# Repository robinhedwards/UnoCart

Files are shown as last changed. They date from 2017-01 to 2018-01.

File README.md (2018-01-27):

UnoCart
=======
The UnoCart is an SD-card multicart for the Atari 8-bit (XL & XE), supporting ROMs,CARs,XEXs and some ATR files.
It is the little brother of the [Ultimate Cart](https://github.com/robinhedwards/UltimateCart/).

The multicart is based on a STM32F4 microcontroller running at 168MHz. This is (just) fast enough to respond to requests
from the Atari's 6502 bus clocked at approximately 2 MHz. Files are loaded from SD card into the STM32F4's SRAM allowing
emulation of Atari cartridges up to 128k in size.

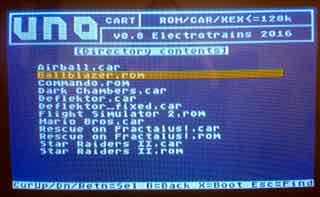
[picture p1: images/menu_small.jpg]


When the Atari first boots, the cartridge displays a list of all the files on the SD card. When a ROM or CAR file is
selected, the cartridge will then emulate the selected cartridge type. The UnoCart supports standard 8k and 16k ROMS,
XEGS cartridges up to 128k in size, AtariMax 1mbit, Bounty Bob, OSS cartridges and many more.

XEX files (Atari executables) are also supported using a XEX loader built into the cartridge.

The cartridge can also emulate a disk drive on an Atari with with at least 64k. It does this by installing a Soft OS into
the Atari which then redirects D1: to the ATR file selected from the menu. Access for D2: upwards continue to be directed
to the SIO port as normal.
Many games will not work, due to the soft OS technique used. However it is possible to boot to a DOS 2.5 ATR file,
do some programming in BASIC and save your program back to the ATR file. ATR files up to 16Meg in size are supported.

Hardware
--------
The UnoCart was first designed using a STM32F407 DISCOVERY board. An article describing how to build an UnoCart using
this board was published in [Excel Magazine](http://excel-retro-mag.co.uk) issue #4.
You can also get a PDF of the article [here](https://github.com/robinhedwards/UnoCart/blob/master/UnoCart_EXCEL4.pdf).

I have also designed a custom PCB for the UnoCart pictured here. If you are interested in a ready to use cartridge (complete with
3d printed case) these are currently being produced by Marlin Bates in the USA: [website](http://www.thebrewingacademy.com/)
or email thebrewingacademy@gmail.com.

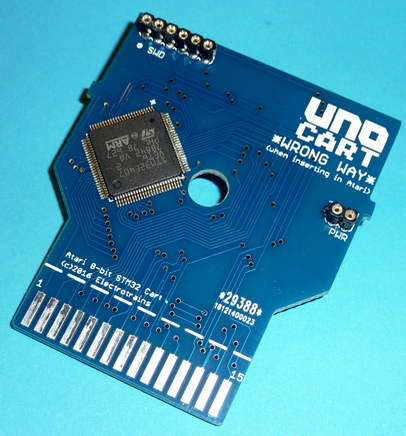
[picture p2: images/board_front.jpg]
Bottom/Back of PCB when inserted in Atari

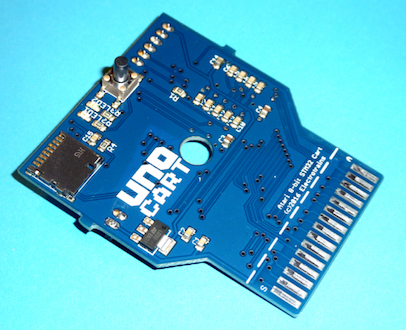
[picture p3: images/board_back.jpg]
Top/Front of PCB when inserted in Atari


Firmware
--------
The UnoCart firmware is open source under a GPL license and is hosted here.

Credits
-------
* Design, hardware and firmware by Robin Edwards (electrotrains at atariage)
* XEX loader and OS modifications by Jonathan Halliday (flashjazzcat at atariage)
* Altirra LLE OS used with permision from Avery Lee (phaeron at atariage)
* German translation of user manual by Florian D (FlorianD at atariage)
* Production by Marlin Bates (MacRorie at atariage)

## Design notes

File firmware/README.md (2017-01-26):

The current UnoCart firmware (v1.2)

For use with ST-Link device and STM32 ST-Link utility (see the user guide for more details).

Changelog

* 2017-01-26 v1.2 Fixed XEX loader bug, added support for CTRL+Cursor keys (CTRL+LEFT = back).
* 2016-12-04 v1.1 Initial version for beta test.

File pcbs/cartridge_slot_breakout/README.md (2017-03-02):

Eagle board file for Atari cartridge slot breakout PCB, which breaks out the cartridge slot to 6 x 5 pin headers (male or female).
For use with Atari XL or XE.

On an XE, the side where the connector is labelled S-A should be facing upwards.
On an XL, the S-A side should be facing forwards.

IMPORTANT - on an XL, you should remove the cartridge slot flaps, or insert something in the slot to keep the flaps away from the PCB. Otherwise you risk a short circuit.

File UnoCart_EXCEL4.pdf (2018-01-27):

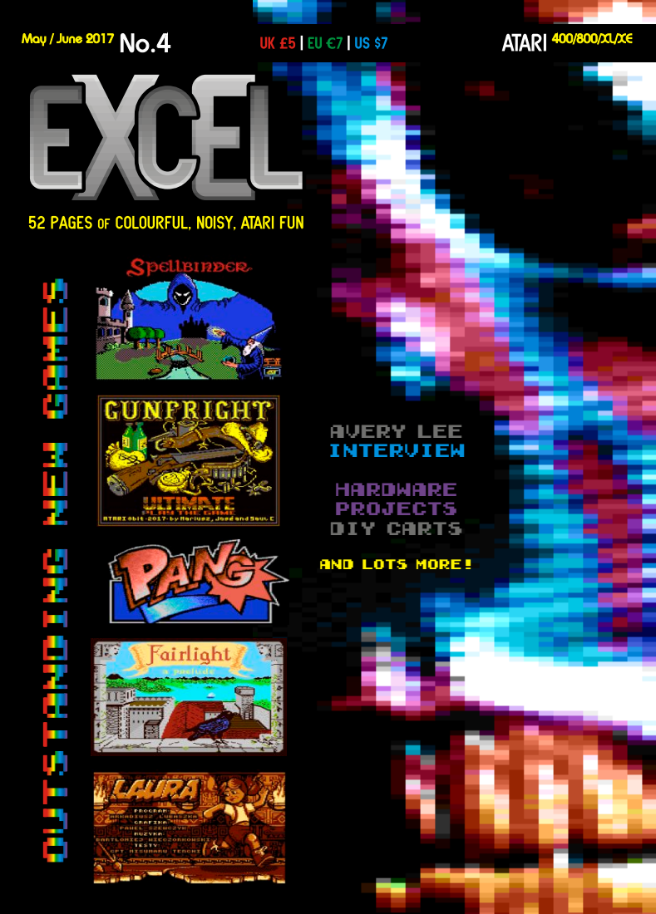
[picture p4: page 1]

OUTSTANDING NEW GAMES

You can read more about the capabilies of the UnoCart by downloading the User Guide which is available as a PDF on the project website (2).

### WHAT YOU NEED

ST32F407 Discovery board. There are two versions of this board – an older one (order code STM32F4DISCOVERY) and a newer version (order STM32F407G-DISC1). Either is suitable and costs about £16.

Cartridge slot breakout board. I’ve designed a PCB that slides into the cartridge slot, allowing the signals to be easily accessed with jumper wires. The PCB can be ordered from a PCB manufacturer using the breakout PCB file on the project website (2). For readers in the USA, the bits of the past website (3) offers a similar board for sale at $15.

I’ve got a number of these boards spare for readers of the magazine, so the cheapest opon is to contact me (robin.edwards@gmail.com) to see if I’ve got any le. Cost would be £3 + P&P.

2.54mm male header pins (x30). If you don’t have these already, they are cheaply (£1) available from eBay and all electronics suppliers, and need to be soldered to the cartridge breakout PCB (see below).

Female to female jumper wires (x36). You’ll need 30 to hook up the cartridge port to the discovery board, and another 6 to hook up the SD card. Mine are 10cm long; a bit longer would have been easier (£2 on eBay).

SD (or micro SD) card breakout board. These are available cheaply on ebay and most online electronics hobbyist websites (£3-5). Since the discovery board is 3.3v (the same as SD cards) there is no need for a more expensive board with 5v conversion (though you can use those too). Something like (4) is ideal. I used a 5v regulated one (5) which I had in my components box.

Make sure the pins on the board you buy are labeled with the SPI connecons –DI, DO, SCK (or CLK) & CS.

Programming the Firmware
First you need to download the UnoCart firmware (a file with a .hex extension) from the project website (2) and save it.

To program this file to the board, download the ST-Link soware (6) and install it. This should also install the ST-Link driver to your computer. With that done you can connect the Discovery board to your computer using a USB cable. Start the ST-Link soware and select

# Building a UNOcart by Robin Edwards

Aer wring about DIY standard 8k and 16k EEPROM based cartridges in my previous column, I wanted to do a follow up arcle with building instrucons for a more flexible and modern mul-cart design.

A mul-cart allows you to put lots of different games (and other soware) on one cartridge and choose what to use from a built-in menu. Many different mul-carts have been made for our Atari 8-bits and most of them require lengthy programming of a (large) EEPROM every me you want to change the contents of the cartridge. Programming is usually done on the Atari with a SIO device as the source. This means these cartridges are not so useful as stand-alone devices and also makes them less than ideal for quickly trying out new soware.
With those issues in mind, a couple of years ago I designed the Ulmate Cart (1) an open-source mul-cart that uses an SD card for storage and is capable of emulang almost all types of cartridge ever released for the Atari 8-bit, including many other mul-carts. But the Ulmate cart requires some costly parts and advanced soldering techniques so it’s not something that most people could easily build by themselves.

So for this arcle, I’m going to describe how to build my newest project – the UnoCart, a mul-cart I designed for readers of Excel magazine. It aims to be cheap (under £30) and easy to put together, yet provide a modern way to access a wide range of soware (old and new) on an unmodified Atari XL or XE.

In many ways, the UnoCart is the lile brother of the Ulmate Cart – it emulates a wide range of cartridges (up to 128k in size), can launch XEX files (executables) and ATR files (disk images), all from a micro SD card.
It does all this using a single chip (hence the name of the project!) – a fast STM32407 ARM microcontroller running at 168MHz. This is fast enough to keep up with the 6502 bus and supply data to the Atari whenever it accesses the cartridge port. These microcontrollers are available ready to use on cheap development boards, so the only soldering involved in this project is making a simple breakout board so we can connect it up to the Atari’s cartridge port.

Target/Connect. Then select Target/Program & Verify and select the .hex file you downloaded. When that completes, the UnoCart firmware will be flashed to your discovery board. Select
Target/Disconnect and then unplug the USB cable – now you’re ready to start wiring things up.

Building
First solder the male header pins to the breakout board PCB, by breaking the header strip up into 6
pieces with 5 pins. Insert these into
the holes in the breakout board and
solder them into place. Noce that the board is labelled S-A on one side and 1-15 on the other. The S-A side of the board will be facing upwards (XE) or towards you (XL) when inserted in an Atari.

For use on XE machines - you’ll need to solder the pins so you will be able to aach the jumper wires to the top of the board (as seen in the picture).

On an XL machine, you may prefer to solder the pins the other way round, so the wires will be leading out towards the back of your machine rather than over the keyboard.

With that done, its me to wire up the 30 connecons on the breakout board to the appropriate pins on the discovery board. The table above shows the connecons you should make. Please check them carefully, since incorrect wiring may damage the discovery board, the Atari or both!

(1) You must disconnect the USB cable from the discovery board when plugging in the device to your Atari. The discovery board must be powered by the Atari via the cartridge slot only, or you will probably destroy the MMU chip on your Atari.
(2) On an XL you should remove the cartridge slot flaps or otherwise prevent them touching the breakout board to prevent a short circuit.

Now we can plug the device into the Atari and check our wiring so far - making sure that the USB cable is not plugged in (see noce above). If all has gone well, you should see the “error can’t read SD card” screen (as shown on the right) when you power up the Atari with the board plugged in. If not, turn the power off quickly and find the mistake in your wiring.

Now we can hook up the SD card connecons.

Connect as follows:

First power up. We haven’t wired up the SD card yet so the error is to be expected!

6

Assembly is now complete – you should be able to plug the board into your Atari, power up and see a list of all the loadable files and directories on the SD card. Use the cursor keys and return to select a XEX, ROM, CAR or ATR file and enjoy!

If everything is working, its now worth downloading the full instrucon manual for the UnoCart from the project website.

Troubleshoong p - Some SD cards fail to inialize without a pull-up resistor on DO. Either try a different SD card or add this pull up by connecng any resistor in the range of 10k to 100k (I used 47k) between DO and 3V. You can see I have soldered this directly onto the SD card breakout board in the picture.

## Links

(1) github.com/robinhedwards/UlmateCart/
(2) github.com/robinhedwards/UnoCart/
(3) www.bitsohepast.com
(4) www.hobbytronics.co.uk/microsd-breakout
(5) www.hobbytronics.co.uk/microsd-card-regulated-v2
(6) www.st.com/en/embedded-soware/stsw-link004.html

Cartridge slot breakout PCB and header strip (le) and assembled version for use
on an Atari XE (right).
The cheapest way to get one is to contact the author and see if he has any spares!

The STM32F407 DISCOVERY board (older version). A lot of power for £16!

### The finished UnoCart plugged into

the back of a 65XE.

The UnoCart menu when everything is working.

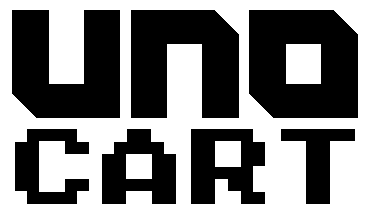
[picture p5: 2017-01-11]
images/UNOcart.bmp

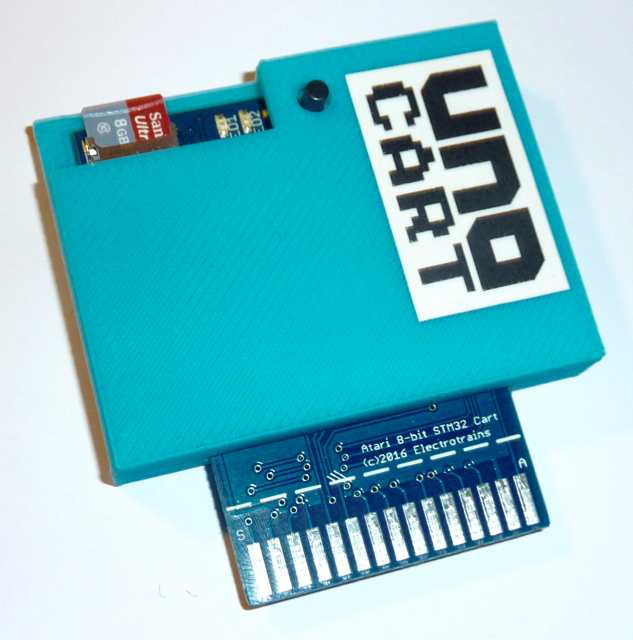
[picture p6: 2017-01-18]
images/cased.jpg

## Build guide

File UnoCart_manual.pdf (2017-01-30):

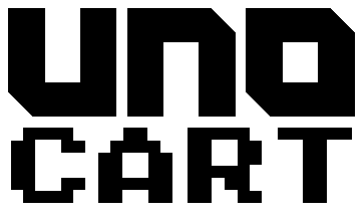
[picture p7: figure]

# Instruction Manual

Revision 1.5 30/1/2017

Atari XL/XE microSD multi-cart

Quick Start
The UnoCart is an Atari cartridge emulator and XEX file launcher. It supports files up to 128k in size. First, copy XEX, CAR and ROM files to a microSD card and insert it into the cartridge. Then insert the cartridge in the Atari 8-bit with the label/SD card slot facing forwards (Atari XL) or upwards (Atari XE). If the board is uncased, check you’ve got it the right way round. Power on the Atari. Use the cursor up and down keys to select an item and press Return to start it. Menu
The menu allows you to navigate the files on a microSD card and select a title to use. Use the cursor up, down and [Return] keys to select items. Press [B] to go back to the parent directory. Press [ESC] to search for a file. Press [X] to disable the cartridge and boot normally (e.g. from a SIO device) – this allows you to leave the cartridge plugged in. Indicator Lights
The red led indicates the cartridge is functioning correctly and is powered. When the menu is active, the green light will indicate SD card access. After a title is selected from the menu, the green light indicates that the cartridge is active.
Reset Button
Press the reset button (next to the SD card slot) to reset the cartridge. This will generally cause the Atari to crash, and the reset button on the Atari can then be pressed to return to the cartridge menu.
CAR Files & ROM Files
CAR files and ROM files both contain the data for a cartridge. However CAR files have an additional 16 bytes header containing the cartridge type making it clearly identifiable to the UnoCart. In contrast, the cartridge type of a ROM file is ambiguous – e.g. an 8k ROM file could be a standard 8K cartridge, or an 8k OSS cartridge.
ROM Files
Plain ROM files are supported, but since these files are raw cartridge dumps, the UnoCart will decide what type of cartridge they come from based on the file size only. The table below shows what types will be used.
ROM File Size | Cartridge Type
8k | Standard Atari 8k
16k | Standard Atari 16k
32k | Atari XEGS 32k
64k | Atari XEGS 64k
128k | Atari XEGS 128k
Supported Cartridge Types (CAR files)
Description | CAR Type(s)
Standard Atari 8k | 1
Standard Atari 16k | 2
Atari XEGS 32-128k | 12-14
AtariMax 1mbit (128k) | 41
Switchable XEGS 32-128k | 33-35
Megacart 16-128k | 26-29
Bounty Bob | 18

Williams 32k, 64k | 8, 22
OSS 8k | 44
OSS 16k (034M) | 3
OSS 16k (043M) | 45
OSS 16k (type B) | 15
SIC!Cart (128k only) | 54
SDX 64k | 11
Diamond 64k | 10
Express 64k | 9
SDX 128k | 43
Blizzard 16k | 40
Converting to CAR format
Utilities are available to convert ROM/BIN files into the CAR file format. The ROM2CAR utility available on the Ultimate cart website provides an easy drag and drop interface: https://github.com/robinhedwards/UltimateCart/ Problem Files
You may come across files with a .BIN extension. These are often just .ROM files and can be renamed. You may also find ROM files where the UnoCart menu gives the error “Unsupported ROM size”. This happens when the ROM file is not an exact multiple of 1,024 bytes. In this case, the ROM dump may have already been converted to a CAR file (with a 16 byte header) but has been wrongly named and you can simply rename the file from .ROM to .CAR.
ATR Files (64k and above XL/XE only)
The cartridge also has simple support for reading and writing to ATR (floppy disk image) files. It supports both SD (128 byte sector) and DD (256 byte sector) images. DD images must be standard ATR files, with 128 bytes for the first 3 sectors and no padding. The device supports ATR files up to 16 megabytes in size.
When an ATR file is selected from the menu, a modified version of the Atari operating system (OS), based on the Altirra open-source LLE kernel, is installed as a “soft” OS in the 16k RAM under the OS – this allows the Atari’s SIO requests to disk drive 1 (D1:) to be re-directed to the SD card in the cartridge.
The main use case for this feature is to allow you to boot a DOS formatted disk (e.g. DOS 2.5) and load and save BASIC programs to the disk. Note that the UnoCart cannot emulate a disk and cartridge at the same time.
In ATR mode, the LEDs on the cartridge indicate SIO reads (green) and writes (red) to the ATR file. Accesses to other disk drives (D2: upwards) are passed through to the SIO port as normal. This allows files to be copied between an ATR mounted on the cartridge (D1:) and other SIO devices (D2:+).
Hold down OPTION when you select the ATR file to disable BASIC. This is necessary for many games. MyPicoDOS ATRs (such as the 16 meg game compilations) will run, but SELECT should be pressed to disable high-speed SIO, and use the operating system SIO routines instead.
Important note – many ATRs will run correctly from the UnoCart. However, any programs that attempt to use the RAM under OS will not work, nor will any software that does not use the standard OS SIO calls.
The OS ROM is stored in the cartridge firmware, but an alternative UNO_OS.ROM file (16k) will be loaded and installed from the root directory of the SD card instead (if such a file is present).

Firmware re-programming (advanced)

The board can be re-programmed using an ST-Link device. The table below shows the pins of the SWD connector on the top left of the board (pin 1 is on the left, marked with a filled circle). Connections in bold are required for programming. The board must also be powered through the +5V pin on the right of the 2-pin power header, not through the +3V3 pin on the programming header to avoid back powering the on-board regulator. The latest firmware is available on the project website: https://github.com/robinhedwards/UnoCart

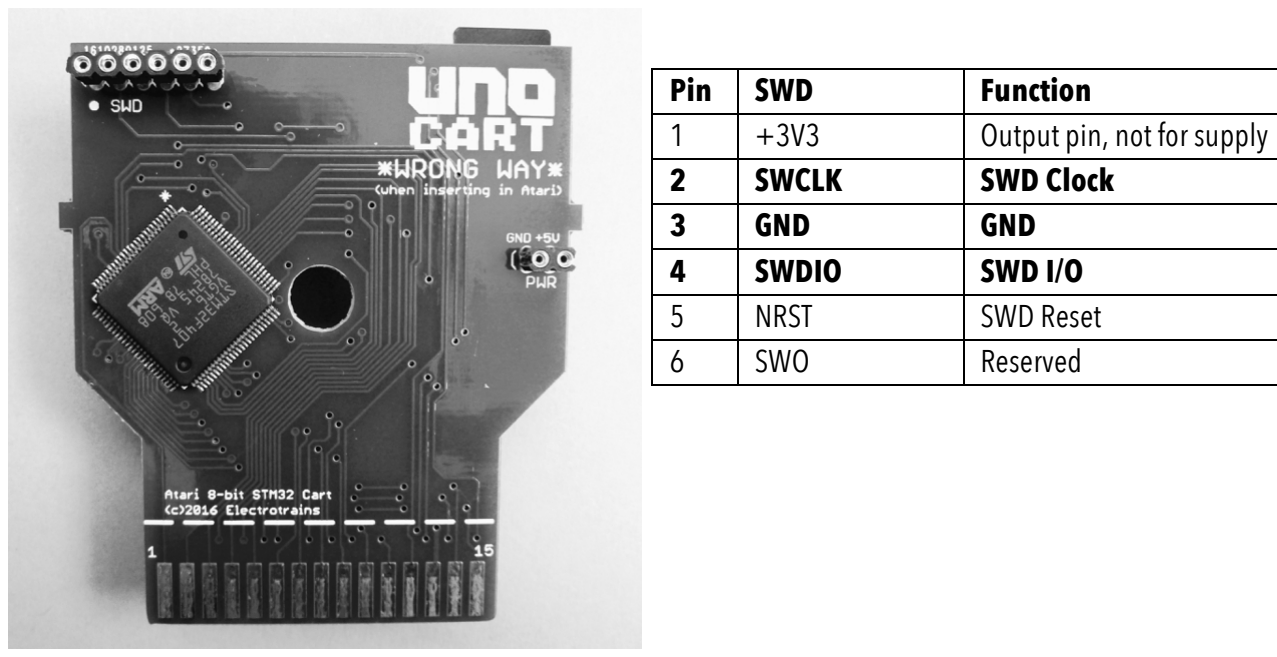
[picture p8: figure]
Pin; SWD; Function; Output pin, not for supply; SWCLK; SWD Clock; GND; SWDIO; SWD I/O; NRST; SWD Reset; SWO; Reserved

Microcontroller (advanced)
The UnoCart will be fitted with either a STM32F407VGT6 (1meg flash) or a STM32F407VET6 (512k flash) microcontroller. Please refer to your PCB to determine which one is present on your device. If you are developing new firmware for the cartridge, the table below shows the pins connected to the cartridge port, LEDs & micro SD card slot.
STM32 Pin(s) | Cartridge Port | STM32 Pin(s) | Function
PD0...12 | A0…A12 | PB0, PB1 | Green and Red LEDs (active high).
PE8…15 | D0…D7 | PB5 | MicroSD CS
PC0 | Phi2 | PB13 (SPI2,2) | MicroSD CLK
PC1 | /S5 | PB14 (SPI2,2) | MicroSD DO
PC2 | /S4 | PB15 (SPI2,2) | MicroSD DI
PC4 | CCTL
PC5 | RW
PB2 | RD5
PB4 | RD4

Credits
Original idea, hardware and firmware by Robin Edwards (electrotrains at atariage). Altirra LLE OS used with permission from Avery Lee (phaeron at atariage). XEX loader, OS modifications and many helpful discussions thanks to Jonathan Halliday (flashjazzcat at atariage).

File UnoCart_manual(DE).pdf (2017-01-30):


# Anleitung

Version 1.5 28/1/2017

Atari 8-bit MicroSD-Card Multi-Modul

### Kurzanleitung

Die UnoCart ist ein Modul-Emulator und .XEX-Datei-Startprogramm für Atari XL und XE Computer. Es unterstützt Dateien bis zu 128kByte Größe. Als erstes kopiert man .XEX-Dateien, .CAR- und .ROM-Dateien auf eine Micro-SD Karte und steckt diese in den Adapter des Moduls. Danach steckt man das Modul in einen Atari XL oder XE. Dabei weist der Aufkleber nach vorne (XL) oder nach oben (XE). Falls das Modul ohne Gehäuse benutzt wird, beachtet man den Aufdruck auf der Platine: „Wrong Way“ muss nach hinten (XL) bzw. nach unten (XE). Danach schaltet man den Atari ein. Durch Benutzen der Pfeiltasten „Aufwärts“ und „Abwärts“ wählt man einen Menüpunkt aus und und drückt [RETURN] um ihn zu starten.

### Menü

Das Menü erlaubt das Ansteuern und Auswählen der Dateien auf der MicroSD-Karte. Verwenden Sie die Tasten [Pfeil aufwärts], [Pfeil abwärts] und [Return], um eine Datei oder ein Verzeichnis auszuwählen. Drücken Sie [B] um wieder in das übergeordnete Verzeichnis zurückzukehren (B = Back). Drücken Sie [Esc], um nach einer Datei zu suchen. Drücken Sie [X], um das Modul auszuschalten und den Computer normal zu booten (zum Beispiel von einem SIO-Gerät); dies ermöglicht, das Modul im Computer eingesteckt zu lassen.

### Anzeigen (LEDs)

Die rote LED zeigt an, dass das Modul korrekt funktioniert und ausreichend mit Strom versorgt wird. Wenn das Menü aktiv ist, zeigt die grüne LED an, dass Zugriff auf die Micro-SD-Karte erfolgt. Nachdem eine Auswahl erfolgt ist, zeigt die grüne LED an, dass das Modul aktiv ist.

### Reset-Knopf

Um das Modul zu resetten (in den Grundzustand zu versetzen), drückt man den RESET-Knopf, der sich neben der Micro-SD-Karte befindet. Dies bringt den Atari grundsätzlich zum Absturz; das ist kein Fehler oder Problem. Danach drückt man RESET am Atari und man gelangt wieder in das Auswahl-Menü des Moduls.

### .CAR-Dateien und .ROM-Dateien

Dateien vom Typ .CAR und .ROM enthalten beide jeweils Daten für ein Modul. Jedoch haben .CAR-Dateien zusätzlich einen 16 Byte langen Header (Vorspann) der Informationen über den Modultyp enthält und es der UnoCart ermöglicht, diese eindeutig zu erkennen. Dagegen ist der Modul-Typ einer .ROM-Datei uneindeutig: zum Beispiel kann eine 8k Rom-Datei entweder ein 8k Standard-Modul sein oder ein 8k OSS-Modul.

### .ROM-Dateien

Einfache .ROM-Dateien werden unterstützt. Da dies einfache 1:1-Speicherabzüge von Modulen sind, entscheidet das Uno-Modul nur aufgrund der Größe, um welchen Modul-Typ es sich handelt. Die folgende Tabelle zeigt, welche Modul-Typen dafür benutzt werden.

ROM Datei Größe | Modul-Typ
8k | Standard Atari 8k
16k | Standard Atari 16k
32k | Atari XEGS 32k
64k | Atari XEGS 64k
128k | Atari XEGS 128k

### Unterstützte Modul-Typen (.CAR-Dateien)

### Konvertieren ins .CAR-Format

Es gibt Utilities (Hilfsprogramme), die .ROM/.BIN-Dateien ins .CAR-Dateiformat umwandeln können. Das Hilfsprogramm ROM2CAR hat eine einfache Drag&Drop Benutzeroberfläche. Es ist auf der Webseite des Ultimate Carts erhältlich: https://github.com/robinhedwards/UltimateCart

### Problematische Dateien

Manchmal gibt es Dateien mit der Endung .BIN. Diese sind oft .ROM-Dateien und können einfach umbenannt werden. Auch kommt es vor, dass .ROM-Dateien von der UnoCart zurückgewiesen werden mit dem Fehler „Unsupported ROM size“ („nicht unterstützte ROM Größe“). Das passiert, wenn die Dateigröße nicht ein ganzes Vielfaches von 1.024 Bytes ist. In diesem Fall könnte es sein, dass die Datei bereits in das .CAR-Format umgewandelt wurde (ein Vielfaches von 1.024 Bytes Daten plus 16 Bytes Header), aber falsch benannte wurde. Versuchen Sie, die Datei auf .CAR umzubenennen und testen Sie die Datei erneut.

### ATR-Dateien (nur für 64k XL/XE)

Das Modul beinhaltet auch eine einfache Unterstützung für das Lesen und Schreiben von ATR-Dateien (Floppy Disk Images). Es unterstützt sowohl Single Density (SD, 128 Bytes pro Sektor) als auch Double Density (DD, 256 Bytes

Beschreibung | CAR Datei-Typ(en)
Standard Atari 8k | 1
Standard Atari 16k | 2
Atari XEGS 32-128k | 12-14
AtariMax 1mbit (128k) | 41
Switchable XEGS 32-128k (Umschaltbare XEGS 32-128k) | 33-35
Megacart 16-128k | 26-29
Bounty Bob | 18
Williams 32k, 64k | 8, 22
OSS 8k | 44
OSS 16k (034M) | 3
OSS 16k (043M) | 45
OSS 16k (type B) | 15
SIC!Cart (nur 128k) | 54
SDX 64k | 11
Diamond 64k | 10
Express 64k | 9
SDX 128k | 43
Blizzard 16k | 40

pro Sektor) Images. DD Images müssen Standard-ATR-Dateien sein, mit 128 Bytes pro Sektor in den ersten drei Sektoren und ohne Padding (Auffüllung der Lücken). Das Modul unterstützt ATR-Dateien bis zu einer Größe von 16 Megabyte.
Wenn eine ATR-Datei im Menü ausgewählt wird, wird eine modifizierte Version des Atari-Betriebssystems in die 16k RAM unter dem OS geladen. Diese basiert auf dem ‚Altirra Open-Source LLE Kernel’ und ermöglicht es den Zugriff auf die Diskettenstation 1 (D1:) auf das Modul umzuleiten.
Der hauptsächliche Nutzungsfall für diese Möglichkeit ist es, eine DOS-formatierte Diskette (z. B. DOS 2.5) zu laden und dann BASIC Programme von dem Diskettenimage zu laden oder auf dieses zu speichern.
Beachten Sie bitte, dass die UnoCart nicht gleichzeitig ein Diskettenimage und ein Modul emulieren kann.
Im ATR Modus zeigen die LEDs Lesezugriffe grün und Schreibzugriffe rot an. Zugriffe auf andere Diskettenstationen (D2: aufwärts) werden weiterhin wie normal an den SIO-Port durchgeleitet. Dies ermöglicht es, Dateien zwischen dem Diskettenimage auf dem Modul (D1:) und anderen SIO-Geräten (D2: aufwärts) zu kopieren.
Halten Sie die [OPTION]-Taste gedrückt, um beim Booten das BASIC auszuschalten. Dies ist bei vielen Spielen nötig. MyPicoDOS ATRs (z. B. wie die 16 Megabyte Spielzesammlungen) laufen ohne Probleme, es sollte aber beim Booten die [SELECT]-Taste gedrückt werden, um das High-Speed-SIO abzuschalten und die Routinen des Betriebssystem zu verwenden.
Wichtiger Hinweis: viele ATR-Dateien laufen problemlos vom UnoCart. Allerdings funktionieren alle Programme nicht, die das RAM unter dem Betriebssystem benutzen. Weiterhin laufen alle Programm nicht, die andere als die Standard SIO-Routinen benutzen.
Das modifizierte Betriebssystem-ROM ist in der Firmware des Modul gespeichert. Wenn allerdings eine Datei mit Namen ‚UNO_OS.ROM‘ (mit 16k Größe) im Hauptverzeichnis auf der MicroSD Karte gespeichert ist, wird diese geladen, wenn ATR Dateien im Menü ausgewählt werden.

### Neuprogrammierung der Firmware (für Fortgeschrittene)

Das UnoCart kann neu über ein ST-Link-Gerät neu programmiert werden. Die Tabelle unten zeigt den Anschluß der SWD (Serial Wire Debug) Pins. Pin 1 ist links in der Ecke und ist mit einem gefüllten Kreis markiert. Die fett gedruckten Anschlüsse werden für die Programmierung benötigt. Die Platine muß darüber hinaus über den rechten Pin des 2-poligen Anschlusses mit Spannung (+5V) versorgt werden, nicht über den 3,3V PWD-Anschluß (um zu verhindern, dass der On-Board Spannungsregler über diesen Weg Spannung erhält).
Die neueste Firmware ist erhältlich auf der Projekt-Webseite: https://github.com/robinhedwards/UnoCart

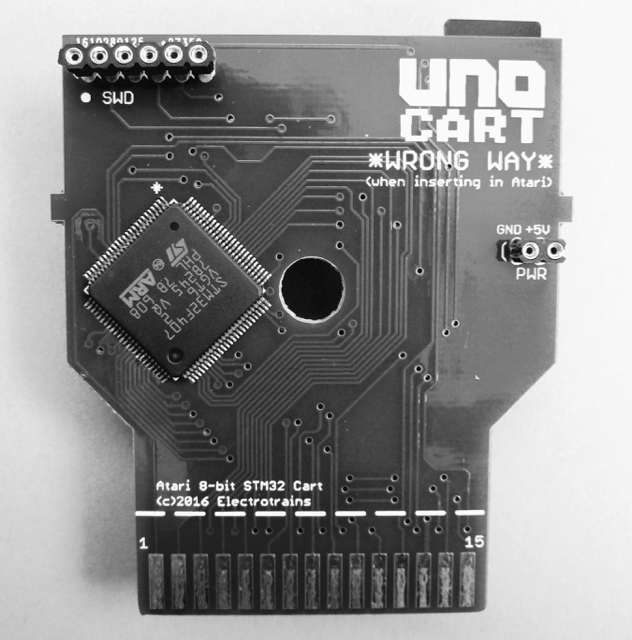
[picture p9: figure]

Pin | SWD | Funktion
1 | +3V3 | Output Pin, nicht für Versorgung
2 | SWCLK | SWD Clock
3 | GND | GND
4 | SWDIO | SWD I/O
5 | NRST | SWD Reset
6 | SWO | Reserviert

### Microcontroller (für Fortgeschrittene)

Das UnoCart ist entweder mit einem STM32F407VGT6 (1meg flash) oder einem STM32F407VET6 (512k flash) Microcontroller ausgestattet. Bitte schauen Sie auf die Platine um festzustellen, was für Ihr Gerät zutrifft. Wenn Sie neue Firmware für das Modul entwickeln, zeigt Ihnen die Tabelle unten, welche Anschlüsse/Pins zum Modulport, zu den LEDs und zum MicroSD Kartenleser gehen.

### Danksagungen

Originale Idee, Hardware und Firmware von Robin Edwards (Username electrotrains bei www.atariage.com). Altirra LLE OS mit freundlichen Genehmigung von Avery Lee (Username phaeron bei www.atariage.com). XEX-Loader, OS-Anpassungen und viele hilfreiche Diskussionen: vielen Dank an Jonathan Halliday (Username flashjazzcat bei www.atariage.com). Florian D. für die Übersetzung ins Deutsche (Username FlorianD bei www.atariage.com).

STM32 Pin(s) | Cartridge Port | STM32 Pin(s) | Function
PD0...12 | A0…A12 | PB0, PB1 | Grüne und Rote LEDs (active high).
PE8…15 | D0…D7 | PB5 | MicroSD CS
PC0 | Phi2 | PB13 (SPI2,2) | MicroSD CLK
PC1 | /S5 | PB14 (SPI2,2) | MicroSD DO
PC2 | /S4 | PB15 (SPI2,2) | MicroSD DI
PC4 | CCTL
PC5 | RW
PB2 | RD5
PB4 | RD4

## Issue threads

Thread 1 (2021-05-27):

EAGLE files

rickyelqasem, 2021-05-27:
I cannot open the pcb in eagle . Is it because the sch file is missing?

rickyelqasem, 2021-05-27:
OK now I have it open but it is not the pcb for the actual unocart right?

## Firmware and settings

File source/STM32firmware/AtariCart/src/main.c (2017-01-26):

/*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
 * You should have received a copy of the GNU General Public License
 * along with this program.  If not, see <http://www.gnu.org/licenses/>.
 */

#define _GNU_SOURCE

#include "defines.h"
#include "stm32f4xx.h"
#include "tm_stm32f4_fatfs.h"
#include "tm_stm32f4_delay.h"
#include <stdio.h>
#include <string.h>

#include "rom.h" /* unsigned char cart_rom[64*1024] */
#include "osrom.h"

unsigned char cart_ram1[64*1024];
unsigned char cart_ram2[64*1024] __attribute__((section(".ccmram")));
unsigned char cart_d5xx[256] = {0};
char errorBuf[40];

#define CART_CMD_OPEN_ITEM			0x00
#define CART_CMD_READ_CUR_DIR		0x01
#define CART_CMD_GET_DIR_ENTRY		0x02
#define CART_CMD_UP_DIR				0x03
#define CART_CMD_ROOT_DIR			0x04
#define CART_CMD_SEARCH				0x05
#define CART_CMD_LOAD_SOFT_OS		0x10
#define CART_CMD_SOFT_OS_CHUNK		0x11
#define CART_CMD_MOUNT_ATR			0x20	// unused, done automatically by firmware
#define CART_CMD_READ_ATR_SECTOR	0x21
#define CART_CMD_WRITE_ATR_SECTOR	0x22
#define CART_CMD_ATR_HEADER			0x23
#define CART_CMD_NO_CART			0xFE
#define CART_CMD_ACTIVATE_CART  	0xFF

#define CART_TYPE_NONE				0
#define CART_TYPE_8K				1	// 8k
#define CART_TYPE_16K				2	// 16k
#define CART_TYPE_XEGS_32K			3	// 32k
#define CART_TYPE_XEGS_64K			4	// 64k
#define CART_TYPE_XEGS_128K			5	// 128k
#define CART_TYPE_SW_XEGS_32K		6	// 32k
#define CART_TYPE_SW_XEGS_64K		7	// 64k
#define CART_TYPE_SW_XEGS_128K		8	// 128k
#define CART_TYPE_MEGACART_16K		9	// 16k
#define CART_TYPE_MEGACART_32K		10	// 32k
#define CART_TYPE_MEGACART_64K		11	// 64k
#define CART_TYPE_MEGACART_128K		12	// 128k
#define CART_TYPE_BOUNTY_BOB		13	// 40k
#define CART_TYPE_ATARIMAX_1MBIT	14	// 128k
#define CART_TYPE_WILLIAMS_64K		15	// 32k/64k
#define CART_TYPE_OSS_16K_TYPE_B	16	// 16k
#define CART_TYPE_OSS_8K			17	// 8k
#define CART_TYPE_OSS_16K_034M		18	// 16k
#define CART_TYPE_OSS_16K_043M		19	// 16k
#define CART_TYPE_SIC_128K			20	// 128k
#define CART_TYPE_SDX_64K			21	// 64k
#define CART_TYPE_SDX_128K			22	// 128k
#define CART_TYPE_DIAMOND_64K		23	// 64k
#define CART_TYPE_EXPRESS_64K		24	// 64k
#define CART_TYPE_BLIZZARD_16K		25	// 16k
#define CART_TYPE_ATR				254
#define CART_TYPE_XEX				255

typedef struct {
	char isDir;
	char filename[13];
	char long_filename[32];
	char full_path[210];
} DIR_ENTRY;	// 256 bytes = 256 entries in 64k

int num_dir_entries = 0; // how many entries in the current directory

int entry_compare(const void* p1, const void* p2)
{
	DIR_ENTRY* e1 = (DIR_ENTRY*)p1;
	DIR_ENTRY* e2 = (DIR_ENTRY*)p2;
	if (e1->isDir && !e2->isDir) return -1;
	else if (!e1->isDir && e2->isDir) return 1;
	else return stricmp(e1->long_filename, e2->long_filename);
}

char *get_filename_ext(char *filename) {
    char *dot = strrchr(filename, '.');
    if(!dot || dot == filename) return "";
    return dot + 1;
}

int is_valid_file(char *filename) {
	char *ext = get_filename_ext(filename);
	if (stricmp(ext, "CAR") == 0 || stricmp(ext, "ROM") == 0
			|| stricmp(ext, "XEX") == 0 || stricmp(ext, "ATR") == 0)
		return 1;
	return 0;
}

// single FILINFO structure
FILINFO fno;
char lfn[_MAX_LFN + 1];   /* Buffer to store the LFN */

void init() {
	// this seems to be required for this version of FAT FS
	fno.lfname = lfn;
	fno.lfsize = sizeof lfn;
}

int scan_files(char *path, char *search)
{
    FRESULT res;
    DIR dir;
    UINT i;

	res = f_opendir(&dir, path);
	if (res == FR_OK) {
		for (;;) {
			if (num_dir_entries == 255) break;
			res = f_readdir(&dir, &fno);
			if (res != FR_OK || fno.fname[0] == 0) break;
			if (fno.fattrib & (AM_HID | AM_SYS)) continue;
			if (fno.fattrib & AM_DIR) {
				i = strlen(path);
				strcat(path, "/");
				strcat(path, fno.fname);
				if (strlen(path) >= 210) continue;	// no more room for path in DIR_ENTRY
				res = scan_files(path, search);
				if (res != FR_OK) break;
				path[i] = 0;
			}
			else if (is_valid_file(fno.fname))
			{
				// copy the 8.3 filename to the LFN if blank
				if (!fno.lfname[0]) strcpy(fno.lfname, fno.fname);
				char *match = strcasestr(fno.lfname, search);
				if (match) {
					DIR_ENTRY *dst = (DIR_ENTRY *)&cart_ram1[0];
					dst += num_dir_entries;
					// fill out a record
					dst->isDir = (match == fno.lfname) ? 1 : 0;	// use this for a "score"
					strcpy(dst->filename, fno.fname);
					strncpy(dst->long_filename, fno.lfname, 31);
					dst->long_filename[31] = 0;
					// full path for search results
					strcpy(dst->full_path, path);

					num_dir_entries++;
				}
			}
		}
		f_closedir(&dir);
	}
	return res;
}

int search_directory(char *path, char *search) {
	char pathBuf[256];
	strcpy(pathBuf, path);
	num_dir_entries = 0;
	int i;
	FATFS FatFs;
	TM_DELAY_Init();
	if (f_mount(&FatFs, "", 1) == FR_OK) {
		if (scan_files(pathBuf, search) == FR_OK) {
			// sort by score, name
			qsort((DIR_ENTRY *)&cart_ram1[0], num_dir_entries, sizeof(DIR_ENTRY), entry_compare);
			DIR_ENTRY *dst = (DIR_ENTRY *)&cart_ram1[0];
			// reset the "scores" back to 0
			for (i=0; i<num_dir_entries; i++)
				dst[i].isDir = 0;
			return 1;

		}
	}
	strcpy(errorBuf, "Problem searching SD card");
	return 0;
}

int read_directory(char *path) {
	int ret = 0;
	num_dir_entries = 0;
	DIR_ENTRY *dst = (DIR_ENTRY *)&cart_ram1[0];

	FATFS FatFs;
	TM_DELAY_Init();
	if (f_mount(&FatFs, "", 1) == FR_OK) {
		DIR dir;
		if (f_opendir(&dir, path) == FR_OK) {
			while (num_dir_entries < 255) {
				if (f_readdir(&dir, &fno) != FR_OK || fno.fname[0] == 0)
					break;
				if (fno.fattrib & (AM_HID | AM_SYS))
					continue;
				dst->isDir = fno.fattrib & AM_DIR ? 1 : 0;
				if (!dst->isDir)
					if (!is_valid_file(fno.fname)) continue;
				// copy file record to first ram block
	            strcpy(dst->filename, fno.fname);
				if (fno.lfname[0]) {
					strncpy(dst->long_filename, fno.lfname, 31);
					dst->long_filename[31] = 0;
				}
				else strcpy(dst->long_filename, fno.fname);
				dst->full_path[0] = 0; // path only for search results
	            dst++;
				num_dir_entries++;
			}
			f_closedir(&dir);
		}
		else
			strcpy(errorBuf, "Can't read directory");
		f_mount(0, "", 1);
		qsort((DIR_ENTRY *)&cart_ram1[0], num_dir_entries, sizeof(DIR_ENTRY), entry_compare);
		ret = 1;
	}
	else
		strcpy(errorBuf, "Can't read SD card");
	return ret;
}

/* ATR Handling */

// ATR format
#define ATR_HEADER_SIZE 16
#define ATR_SIGNATURE 0x0296
typedef struct {
  uint16_t signature;
  uint16_t pars;
  uint16_t secSize;
  uint16_t parsHigh;
  uint8_t flags;
  uint16_t protInfo;
  uint8_t unused[5];
} ATRHeader;

typedef struct {
	char path[256];
	ATRHeader atrHeader;
	int	filesize;
	FIL fil;
} MountedATR;

MountedATR mountedATRs[1] = {0};

FATFS FatFs;
int doneFatFsInit = 0;

int mount_atr(char *filename) {
	// returns 0 for success or error code
	// 1 = no media, 2 = no file, 3 = bad atr
	if (!doneFatFsInit) {
		if (f_mount(&FatFs, "", 1) != FR_OK)
			return 1;
		doneFatFsInit = 1;
	}
	MountedATR *mountedATR = &mountedATRs[0];
	if (f_open(&mountedATR->fil, filename, FA_READ|FA_WRITE) != FR_OK)
		return 2;
	UINT br;
	if (f_read(&mountedATR->fil, &mountedATR->atrHeader, ATR_HEADER_SIZE, &br) != FR_OK || br != ATR_HEADER_SIZE ||
			mountedATR->atrHeader.signature != ATR_SIGNATURE) {
		f_close(&mountedATR->fil);
		return 3;
	}
	// success
	strcpy(mountedATR->path, filename);
	mountedATR->filesize = f_size(&mountedATR->fil);
	return 0;
}

int read_atr_sector(uint16_t sector, uint8_t page, uint8_t *buf) {
	// returns 0 for success or error code
	// 1 = no ATR mounted, 2 = invalid sector
	MountedATR *mountedATR = &mountedATRs[0];
	if (!mountedATR->path[0]) return 1;
	if (sector == 0) return 2;

	int offset = ATR_HEADER_SIZE;
	// first 3 sectors are always 128 bytes
	if (sector <=3)
		offset += (sector - 1) * 128;
	else
		offset += (3 * 128) + ((sector - 4) * mountedATR->atrHeader.secSize) + (page * 128);
	// check we're not reading beyond the end of the file..
	if (offset > (mountedATR->filesize - 128)) {
		memset(buf, 0 , 128);	// return blank sector?
		return 0;
	}
	UINT br;
	if (f_lseek(&mountedATR->fil, offset) != FR_OK || f_read(&mountedATR->fil, buf, 128, &br) != FR_OK || br != 128)
		return 2;
	return 0;
}

int write_atr_sector(uint16_t sector, uint8_t page, uint8_t *buf) {
	// returns 0 for success or error code
	// 1 = no ATR mounted, 2 = write error
	MountedATR *mountedATR = &mountedATRs[0];
	if (!mountedATR->path[0]) return 1;
	if (sector == 0) return 2;

	int offset = ATR_HEADER_SIZE;
	// first 3 sectors are always 128 bytes
	if (sector <=3)
		offset += (sector - 1) * 128;
	else
		offset += (3 * 128) + ((sector - 4) * mountedATR->atrHeader.secSize) + (page * 128);
	// check we're not writing beyond the end of the file..
	if (offset > (mountedATR->filesize - 128))
		return 2;
	UINT bw;
	if (f_lseek(&mountedATR->fil, offset) != FR_OK || f_write(&mountedATR->fil, buf, 128, &bw) != FR_OK || f_sync(&mountedATR->fil) != FR_OK  || bw != 128)
		return 2;
	return 0;
}

/* CARTRIDGE/XEX HANDLING */

int load_file(char *filename) {
	TM_DELAY_Init();
	FATFS FatFs;
	int cart_type = CART_TYPE_NONE;
	int car_file = 0, xex_file = 0, expectedSize = 0;
	unsigned char carFileHeader[16];
	UINT br, size = 0;

	if (strncasecmp(filename+strlen(filename)-4, ".CAR", 4) == 0)
		car_file = 1;
	if (strncasecmp(filename+strlen(filename)-4, ".XEX", 4) == 0)
		xex_file = 1;

	if (f_mount(&FatFs, "", 1) != FR_OK) {
		strcpy(errorBuf, "Can't read SD card");
		return 0;
	}
	FIL fil;
	if (f_open(&fil, filename, FA_READ) != FR_OK) {
		strcpy(errorBuf, "Can't open file");
		goto cleanup;
	}

	// read the .CAR file header?
	if (car_file) {
		if (f_read(&fil, carFileHeader, 16, &br) != FR_OK || br != 16) {
			strcpy(errorBuf, "Bad CAR file");
			goto closefile;
		}
		int car_type = carFileHeader[7];
		if (car_type == 1)			{ cart_type = CART_TYPE_8K; expectedSize = 8192; }
		else if (car_type == 2)		{ cart_type = CART_TYPE_16K; expectedSize = 16384; }
		else if (car_type == 3) 	{ cart_type = CART_TYPE_OSS_16K_034M; expectedSize = 16384; }
		else if (car_type == 8)		{ cart_type = CART_TYPE_WILLIAMS_64K; expectedSize = 65536; }
		else if (car_type == 9)		{ cart_type = CART_TYPE_EXPRESS_64K; expectedSize = 65536; }
		else if (car_type == 10)	{ cart_type = CART_TYPE_DIAMOND_64K; expectedSize = 65536; }
		else if (car_type == 11)	{ cart_type = CART_TYPE_SDX_64K; expectedSize = 65536; }
		else if (car_type == 12) 	{ cart_type = CART_TYPE_XEGS_32K; expectedSize = 32768; }
		else if (car_type == 13) 	{ cart_type = CART_TYPE_XEGS_64K; expectedSize = 65536; }
		else if (car_type == 14) 	{ cart_type = CART_TYPE_XEGS_128K; expectedSize = 131072; }
		else if (car_type == 15) 	{ cart_type = CART_TYPE_OSS_16K_TYPE_B; expectedSize = 16384; }
		else if (car_type == 18) 	{ cart_type = CART_TYPE_BOUNTY_BOB; expectedSize = 40960; }
		else if (car_type == 22)	{ cart_type = CART_TYPE_WILLIAMS_64K; expectedSize = 32768; }
		else if (car_type == 26)	{ cart_type = CART_TYPE_MEGACART_16K; expectedSize = 16384; }
		else if (car_type == 27)	{ cart_type = CART_TYPE_MEGACART_32K; expectedSize = 32768; }
		else if (car_type == 28)	{ cart_type = CART_TYPE_MEGACART_64K; expectedSize = 65536; }
		else if (car_type == 29)	{ cart_type = CART_TYPE_MEGACART_128K; expectedSize = 131072; }
		else if (car_type == 33)	{ cart_type = CART_TYPE_SW_XEGS_32K; expectedSize = 32768; }
		else if (car_type == 34)	{ cart_type = CART_TYPE_SW_XEGS_64K; expectedSize = 65536; }
		else if (car_type == 35)	{ cart_type = CART_TYPE_SW_XEGS_128K; expectedSize = 131072; }
		else if (car_type == 40)	{ cart_type = CART_TYPE_BLIZZARD_16K; expectedSize = 16384; }
		else if (car_type == 41)	{ cart_type = CART_TYPE_ATARIMAX_1MBIT; expectedSize = 131072; }
		else if (car_type == 43)	{ cart_type = CART_TYPE_SDX_128K; expectedSize = 131072; }
		else if (car_type == 44)	{ cart_type = CART_TYPE_OSS_8K; expectedSize = 8192; }
		else if (car_type == 45) 	{ cart_type = CART_TYPE_OSS_16K_043M; expectedSize = 16384; }
		else if (car_type == 54)	{ cart_type = CART_TYPE_SIC_128K; expectedSize = 131072; }
		else {
			strcpy(errorBuf, "Unsupported CAR type");
			goto closefile;
		}
	}

	// set a default error
	strcpy(errorBuf, "Can't read file");

	unsigned char *dst = &cart_ram1[0];
	int bytes_to_read = 64 * 1024;
	if (xex_file) {
		dst += 4;	// leave room for the file length at the start of sram
		bytes_to_read -= 4;
	}
	// read the file in two 64k chunks to each area of SRAM
	if (f_read(&fil, dst, bytes_to_read, &br) != FR_OK) {
		cart_type = CART_TYPE_NONE;
		goto closefile;
	}
	size += br;
	if (br == bytes_to_read) {
		// first 64k was complete, so try to load 64k more
		if (f_read(&fil, &cart_ram2[0], 64*1024, &br) != FR_OK) {
			cart_type = CART_TYPE_NONE;
			goto closefile;
		}
		size += br;
		if (br == 64*1024) {
			// that's 128k read, is there any more?
			if (f_read(&fil, carFileHeader, 1, &br) != FR_OK) {
				cart_type = CART_TYPE_NONE;
				goto closefile;
			}
			if	(br == 1) {
				strcpy(errorBuf, "Cart file/XEX too big (>128k)");
				cart_type = CART_TYPE_NONE;
				goto closefile;
			}
		}
	}

	// set the correct cart type based on the size
	if (car_file) {
		if (size != expectedSize) {
			strcpy(errorBuf, "CAR file is wrong size");
			cart_type = CART_TYPE_NONE;
			goto closefile;
		}
	}
	else if (xex_file) {
		cart_type = CART_TYPE_XEX;
		// stick the size of the file as the first 4 bytes (little endian)
		cart_ram1[0] = size & 0xFF;
		cart_ram1[1] = (size >> 8) & 0xFF;
		cart_ram1[2] = (size >> 16) & 0xFF;
		cart_ram1[3] = 0;	// has to be zero!
	}
	else {	// not a car/xex file - guess the type based on size
		if (size == 8*1024) cart_type = CART_TYPE_8K;
		else if (size == 16*1024) cart_type = CART_TYPE_16K;
		else if (size == 32*1024) cart_type = CART_TYPE_XEGS_32K;
		else if (size == 64*1024) cart_type = CART_TYPE_XEGS_64K;
		else if (size == 128*1024) cart_type = CART_TYPE_XEGS_128K;
		else {
			strcpy(errorBuf, "Unsupported ROM size ");
			cart_type = CART_TYPE_NONE;
			goto closefile;
		}
	}

closefile:
	f_close(&fil);
cleanup:
	f_mount(0, "", 1);
	return cart_type;
}

#define RD5_LOW GPIOB->BSRRH = GPIO_Pin_2;
#define RD4_LOW GPIOB->BSRRH = GPIO_Pin_4;
#define RD5_HIGH GPIOB->BSRRL = GPIO_Pin_2;
#define RD4_HIGH GPIOB->BSRRL = GPIO_Pin_4;

#define CONTROL_IN GPIOC->IDR
#define ADDR_IN GPIOD->IDR
#define DATA_IN GPIOE->IDR
#define DATA_OUT GPIOE->ODR

#define PHI2_RD (GPIOC->IDR & 0x0001)
#define S5_RD (GPIOC->IDR & 0x0002)
#define S4_RD (GPIOC->IDR & 0x0004)
#define S4_AND_S5_HIGH (GPIOC->IDR & 0x0006) == 0x6

#define PHI2	0x0001
#define S5		0x0002
#define S4		0x0004
#define CCTL	0x0010
#define RW		0x0020

#define SET_DATA_MODE_IN GPIOE->MODER = 0x00000000;
#define SET_DATA_MODE_OUT GPIOE->MODER = 0x55550000;

#define GREEN_LED_OFF GPIOB->BSRRH = GPIO_Pin_0;
#define RED_LED_OFF GPIOB->BSRRH = GPIO_Pin_1;
#define GREEN_LED_ON GPIOB->BSRRL = GPIO_Pin_0;
#define RED_LED_ON GPIOB->BSRRL = GPIO_Pin_1;

GPIO_InitTypeDef  GPIO_InitStructure;

/* Green LED -> PB0, Red LED -> PB1, RD5 -> PB2, RD4 -> PB4 */
void config_gpio_leds_RD45()
{
	/* GPIOB Periph clock enable */
	RCC_AHB1PeriphClockCmd(RCC_AHB1Periph_GPIOB, ENABLE);
	/* Configure PB0, PB1in output pushpull mode */
	GPIO_InitStructure.GPIO_Pin = GPIO_Pin_0 | GPIO_Pin_1 | GPIO_Pin_2 | GPIO_Pin_4;
	GPIO_InitStructure.GPIO_Mode = GPIO_Mode_OUT;
	GPIO_InitStructure.GPIO_OType = GPIO_OType_PP;
	GPIO_InitStructure.GPIO_Speed = GPIO_Speed_25MHz;
	GPIO_InitStructure.GPIO_PuPd = GPIO_PuPd_NOPULL;
	GPIO_Init(GPIOB, &GPIO_InitStructure);
}

/* Input Signals GPIO pins on CLK -> PC0, /S5 -> PC1, /S4 ->PC2, CCTL -> PC4, R/W -> PC5 */
void config_gpio_sig(void) {
	/* GPIOC Periph clock enable */
	RCC_AHB1PeriphClockCmd(RCC_AHB1Periph_GPIOC, ENABLE);

	/* Configure GPIO Settings */
	GPIO_InitStructure.GPIO_Pin = GPIO_Pin_0 | GPIO_Pin_1 | GPIO_Pin_2 | GPIO_Pin_4 | GPIO_Pin_5;
	GPIO_InitStructure.GPIO_Mode = GPIO_Mode_IN;
	GPIO_InitStructure.GPIO_OType = GPIO_OType_PP;
	GPIO_InitStructure.GPIO_Speed = GPIO_Speed_100MHz;
	GPIO_InitStructure.GPIO_PuPd = GPIO_PuPd_DOWN;
	GPIO_Init(GPIOC, &GPIO_InitStructure);
}

/* Input/Output data GPIO pins on PE{8..15} */
void config_gpio_data(void) {
	/* GPIOE Periph clock enable */
	RCC_AHB1PeriphClockCmd(RCC_AHB1Periph_GPIOE, ENABLE);

	/* Configure GPIO Settings */
	GPIO_InitStructure.GPIO_Pin =
		GPIO_Pin_8 | GPIO_Pin_9 | GPIO_Pin_10 | GPIO_Pin_11 |
		GPIO_Pin_12 | GPIO_Pin_13 | GPIO_Pin_14 | GPIO_Pin_15;
	GPIO_InitStructure.GPIO_Mode = GPIO_Mode_IN;
	GPIO_InitStructure.GPIO_OType = GPIO_OType_PP;
	GPIO_InitStructure.GPIO_Speed = GPIO_Speed_25MHz;	// avoid sharp edges
	GPIO_InitStructure.GPIO_PuPd = GPIO_PuPd_DOWN;
	GPIO_Init(GPIOE, &GPIO_InitStructure);
}

/* Input Address GPIO pins on PD{0..15} */
void config_gpio_addr(void) {
	/* GPIOD Periph clock enable */
	RCC_AHB1PeriphClockCmd(RCC_AHB1Periph_GPIOD, ENABLE);

	/* Configure GPIO Settings */
	GPIO_InitStructure.GPIO_Pin =
		GPIO_Pin_0 | GPIO_Pin_1 | GPIO_Pin_2 | GPIO_Pin_3 |
		GPIO_Pin_4 | GPIO_Pin_5 | GPIO_Pin_6 | GPIO_Pin_7 |
		GPIO_Pin_8 | GPIO_Pin_9 | GPIO_Pin_10 | GPIO_Pin_11 |
		GPIO_Pin_12 | GPIO_Pin_13 | GPIO_Pin_14 | GPIO_Pin_15;
	GPIO_InitStructure.GPIO_Mode = GPIO_Mode_IN;
	GPIO_InitStructure.GPIO_OType = GPIO_OType_PP;
	GPIO_InitStructure.GPIO_Speed = GPIO_Speed_100MHz;
	GPIO_InitStructure.GPIO_PuPd = GPIO_PuPd_DOWN;
	GPIO_Init(GPIOD, &GPIO_InitStructure);
}
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
int main(void) {
	/* Ouptut: LEDS - PB{0..1}, RD5 - PB2, RD4 - PB4 */
	config_gpio_leds_RD45();
	/* InOut: Data - PE{8..15} */
	config_gpio_data();
	/* In: Address - PD{0..15} */
	config_gpio_addr();
	/* In: Other Cart Input Sigs - PC{0..2, 4..5} */
	config_gpio_sig();

	RED_LED_ON
	int cartType = 0, atrMode = 0;
	char curPath[256] = "";
	char path[256];
	init();

	while (1) {
		GREEN_LED_OFF

		int cmd = emulate_boot_rom(atrMode);

		GREEN_LED_ON

		// OPEN ITEM n
		if (cmd == CART_CMD_OPEN_ITEM)
		{
			int n = cart_d5xx[0x00];
			DIR_ENTRY *entry = (DIR_ENTRY *)&cart_ram1[0];
			if (entry[n].isDir)
			{	// directory
				strcat(curPath, "/");
				strcat(curPath, entry[n].filename);
				cart_d5xx[0x01] = 0; // path changed
			}
			else
			{	// file/search result
				if (entry[n].full_path[0])
					strcpy(path, entry[n].full_path);	// search result
				else
					strcpy(path, curPath); // file in current directory
				strcat(path, "/");
				strcat(path, entry[n].filename);
				if (stricmp(get_filename_ext(entry[n].filename), "ATR")==0)
				{	// ATR
					cart_d5xx[0x01] = 3;	// ATR
					cartType = CART_TYPE_ATR;
				}
				else
				{	// ROM,CAR or XEX
					cartType = load_file(path);
					if (cartType)
						cart_d5xx[0x01] = (cartType != CART_TYPE_XEX ? 1 : 2);	// file was loaded
					else
					{
						cart_d5xx[0x01] = 4;	// error
						strcpy((char*)&cart_d5xx[0x02], errorBuf);
					}
				}
			}
		}
		// READ DIR
		else if (cmd == CART_CMD_READ_CUR_DIR)
		{
			int ret = read_directory(curPath);
			if (ret) {
				cart_d5xx[0x01] = 0;	// ok
				cart_d5xx[0x02] = num_dir_entries;
			}
			else
			{
				cart_d5xx[0x01] = 1;	// error
				strcpy((char*)&cart_d5xx[0x02], errorBuf);
			}
		}
		// GET DIR ENTRY n
		else if (cmd == CART_CMD_GET_DIR_ENTRY)
		{
			int n = cart_d5xx[0x00];
			DIR_ENTRY *entry = (DIR_ENTRY *)&cart_ram1[0];
			cart_d5xx[0x01] = entry[n].isDir;
			strcpy((char*)&cart_d5xx[0x02], entry[n].long_filename);
		}
		// UP A DIRECTORY LEVEL
		else if (cmd == CART_CMD_UP_DIR)
		{
			int len = strlen(curPath);
			while (len && curPath[--len] != '/');
			curPath[len] = 0;
		}
		// ROOT DIR (when atari reset pressed)
		else if (cmd == CART_CMD_ROOT_DIR)
			curPath[0] = 0;
		// SEARCH str
		else if (cmd == CART_CMD_SEARCH)
		{
			char searchStr[32];
			strcpy(searchStr, (char*)&cart_d5xx[0x00]);
			int ret = search_directory(curPath, searchStr);
			if (ret) {
				cart_d5xx[0x01] = 0;	// ok
				cart_d5xx[0x02] = num_dir_entries;
			}
			else
			{
				cart_d5xx[0x01] = 1;	// error
				strcpy((char*)&cart_d5xx[0x02], errorBuf);
			}
		}
		else if (cmd == CART_CMD_LOAD_SOFT_OS)
		{
			int ret = load_file("UNO_OS.ROM");
			if (!ret) {
				for (int i=0; i<16384; i++)
					cart_ram1[i] = os_rom[i];
			}
			cart_d5xx[0x01] = 0;	// ok
		}
		else if (cmd == CART_CMD_SOFT_OS_CHUNK)
		{
			int n = cart_d5xx[0x00];
			for (int i=0; i<128; i++)
				cart_d5xx[0x01+i]=cart_ram1[n*128+i];
		}
		else if (cmd == CART_CMD_READ_ATR_SECTOR)
		{
			//uint8_t device = cart_d5xx[0x00];
			uint16_t sector = (cart_d5xx[0x02] << 8) | cart_d5xx[0x01];
			uint8_t offset = cart_d5xx[0x03];	// 0 = first 128 byte "page", 1 = second, etc
			int ret = read_atr_sector(sector, offset, &cart_d5xx[0x02]);
			cart_d5xx[0x01] = ret;
		}
		else if (cmd == CART_CMD_WRITE_ATR_SECTOR)
		{
			//uint8_t device = cart_d5xx[0x00];
			GREEN_LED_OFF
			RED_LED_ON
			uint16_t sector = (cart_d5xx[0x02] << 8) | cart_d5xx[0x01];
			uint8_t offset = cart_d5xx[0x03];	// 0 = first 128 byte "page", 1 = second, etc
			int ret = write_atr_sector(sector, offset, &cart_d5xx[0x04]);
			cart_d5xx[0x01] = ret;
			RED_LED_OFF
		}
		else if (cmd == CART_CMD_ATR_HEADER)
		{
			//uint8_t device = cart_d5xx[0x00];
			if (!&mountedATRs[0].path[0])
				cart_d5xx[0x01] = 1;
			else
			{
				memcpy(&cart_d5xx[0x02], &mountedATRs[0].atrHeader, 16);
				cart_d5xx[0x01] = 0;
			}
		}
		// NO CART
		else if (cmd == CART_CMD_NO_CART)
			cartType = 0;
		// REBOOT TO CART
		else if (cmd == CART_CMD_ACTIVATE_CART)
		{
			if (cartType == CART_TYPE_ATR) {
				atrMode = 1;
				RED_LED_OFF
				int ret = mount_atr(path);
				if (ret == 0)
					memcpy(&cart_d5xx[0x02], &mountedATRs[0].atrHeader, 16);
				cart_d5xx[0x01] = ret;
			}
			else
				emulate_cartridge(cartType);
		}
	}

}

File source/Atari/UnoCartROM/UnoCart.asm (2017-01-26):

/* Boot ROM for UnoCart
 * by Robin Edwards/Electrotrains@AtariAge
 * This file builds with WUDSN/MADS into an 8K Atari ROM
 * The 8k ROM should be converted into a C include file using:
 *  xxd -i UnoCart.ROM > rom.h
 */

/*
 Theory of Operation
 -------------------
 Atari sends command to mcu on cart by writing to $D5DF ($D5E0-$D5FF = SDX)
 (extra paramters for the command in $D500-$D5DE)
 Atari must be running from RAM when it sends a command, since the mcu on the cart will
 go away at that point.
 Atari polls $D500 until it reads $11. At this point it knows the mcu is back
 and it is safe to rts back to code in cartridge ROM again.
 Results of the command are in $D501-$D5DF
*/

CART_CMD_OPEN_ITEM = $0
CART_CMD_READ_CUR_DIR = $1
CART_CMD_GET_DIR_ENTRY = $2
CART_CMD_UP_DIR = $3
CART_CMD_ROOT_DIR = $4
CART_CMD_SEARCH = $5
CART_CMD_LOAD_SOFT_OS = $10
CART_CMD_SOFT_OS_CHUNK = $11
CART_CMD_NO_CART = $FE
CART_CMD_ACTIVATE_CART = $FF

DIR_START_ROW = 7
DIR_END_ROW = 21
ITEMS_PER_PAGE = DIR_END_ROW-DIR_START_ROW+1

;@com.wudsn.ide.asm.outputfileextension=.rom

;CARTCS	= $bffa                    ;Start address vector, used if CARTFG has CARTFG_START_CART bit set
;CART	= $bffc                    ;Flag, must be zero for modules
;CARTFG	= $bffd                    ;Flags or-ed together, indicating how to start the module.
;CARTAD	= $bffe                    ;Initialization address vector

CARTFG_DIAGNOSTIC_CART = $80       ;Flag value: Directly jump via CARTAD during RESET.
CARTFG_START_CART      = $04       ;Flag value: Jump via CARTAD and then via CARTCS.
CARTFG_BOOT            = $01       ;Flag value: Boot peripherals, then start the module.

COLDSV = $E477				; Coldstart (powerup) entry point
WARMSV = $E474				; Warmstart entry point
CH = $2FC				; Internal hardware value for the last key pressed
BOOT = $09
CASINI = $02
OSROM = $C000
PORTB = $D301
NMIEN = $D40E
PMBASE = $D407
SDMCTL = $22F
GPRIOR = $26F
PCOLR0 = $2C0
PCOLR1 = $2C1
PCOLR2 = $2C2
PCOLR3 = $2C3
COLOR0 = $2C4
COLOR1 = $2C5
COLOR2 = $2C6
COLOR3 = $2C7
COLOR4 = $2C8

HPosP0	equ $D000
HPosP1	equ $D001
HPosP2	equ $D002
HPosP3	equ $D003
HPosM0	equ $D004
HPosM1	equ $D005
HPosM2	equ $D006
HPosM3	equ $D007
SizeP0	equ $D008
SizeP1	equ $D009
SizeP2	equ $D00A
SizeP3	equ $D00B
SizeM	equ $D00C
GrafP0	equ $D00D
GrafP1	equ $D00E
GrafP2	equ $D00F
GrafP3	equ $D010
Trig0	equ $D010
GRACTL	equ $D01D

sm_ptr = $58				; screen memory
search_string = $600
wait_for_cart = $620			; routine copied here
reboot_to_selected_cart = $630		; routine copied here

PMBuffer = $800
Player0Data = $A00
Player1Data = $A80
Player2Data = $B00
Player3Data = $B80

; ************************ VARIABLES ****************************
num_dir_entries = $80
dir_entry	= $81
ypos		= $82
cur_ypos	= $83
top_item	= $84
cur_item	= $85
search_text_len	= $86
search_results_mode = $87
tmp_ptr		= $90	// word
text_out_x	= $92	// word
text_out_y	= $94	// word
text_out_ptr	= $96	// word
text_out_len	= $98
cur_chunk	= $99

; XEX loader stuff from Jon Halliday/FJC
LoaderAddress	equ $700
VER_MAJ		equ $01
VER_MIN		equ $02
FMSZPG		equ $43
Critic		equ $42
IOPtr		equ FMSZPG
FileSize	equ FMSZPG+2 ; .ds 4
ptr1		equ FMSZPG
ptr2		equ FMSZPG+2
ptr3		equ FMSZPG+4
DOSINI		equ $0C
MEMLO		equ $02E7
RunVec		equ $02E0
IniVec		equ $02E2
VCOUNT		equ $D40B
WSYNC		equ $D40A
GINTLK		equ $03FA
TRIG3		equ $D013
SDLSTL		equ $230
CIOV		equ $E456

;	CIO Error Codes
	.enum IOErr
AlreadyOpen	= 129
NotOpen		= 133
EOF		= 136
NAK		= 139
NoFunction	= 146
BadName		= 165
NotFound	= 170
	.ende
	
	.struct IOCBlock
ID		.byte
DevNum		.byte
Command		.byte
Status		.byte
Address		.word
Put		.word	; put byte address
Len		.word
Aux1		.byte 	
Aux2		.byte
Aux3		.byte
Aux4		.byte
Aux5		.byte
Aux6		.byte
	.ends
	
	org $0340

IOCB	dta IOCBlock [8]

;	CIO commands

	.enum IOCommand
Open	= $03
GetText	= $05
Read	= $07
PutText	= $09
Write	= $0B
Close	= $0C
Status	= $0D
	.ende
	
; ************************ CODE ****************************


        opt h-                     ;Disable Atari COM/XEX file headers

        org $a000                  ;RD5 cartridge base
        opt f+                     ;Activate fill mode

;Cartridge initalization
;Only the minimum of the OS initialization is complete, you don't want to code here normally.
init    .proc
        rts
        .endp ; proc init
	
;Cartridge start
;RAM, graphics 0 and IOCB no for the editor (E:) are ready
start   .proc
	mva #$8F COLOR1
	mva #$82 COLOR2
	
	mva #3 BOOT ; patch reset - from mapping the atari (revised) appendix 11
	mwa #reset_routine CASINI
	
        jsr display_boot_screen
	jsr copy_wait_for_cart
	jsr copy_reboot_to_selected_cart
	jsr setup_pmg
	
; read directory
read_current_directory
	mva #0 search_results_mode
	lda #CART_CMD_READ_CUR_DIR
	jsr wait_for_cart
check_read_dir
	lda $D501
	cmp #1	; check for error flag
	bne read_dir_ok
	jsr display_error_msg_from_cart
	jmp read_current_directory
	
read_dir_ok
	lda $D502
	sta num_dir_entries
	mva #0 top_item
	mva #0 cur_item
	
; display_directory
display_directory
	jsr output_header_text
	jsr clear_screen
	
	lda num_dir_entries
	bne dir_ok
	
no_dir	jsr output_empty_dir_msg
	jsr hide_pmg_cursor
	jmp main_loop
	
dir_ok	jsr output_directory
	jsr draw_cursor
	
main_loop
	jsr GetKey
	beq main_loop
	cmp #$1C ; cur up
	beq up_pressed
	cmp #'-'
	beq up_pressed
	
	cmp #$1D ; cur down
	beq down_pressed
	cmp #'='
	beq down_pressed
	
	cmp #'b'
	bne _1
	jmp back_pressed
_1	cmp #$1E ; cur left
	bne _2 
	jmp back_pressed

_2	cmp #$9B ; ret
	bne _3
	jmp return_pressed

_3	cmp #'x'
	bne _4
	jmp disable_pressed

_4	cmp #$1B ; esc
	bne _5
	jmp search_pressed

_5	jmp main_loop

down_pressed
	lda cur_item
	clc
	adc #1
	cmp num_dir_entries
	bcs main_loop
; single row down
	inc cur_item
; do we need to page down?
	lda cur_item
	sec
	sbc top_item
	clc	
	cmp #ITEMS_PER_PAGE
	beq page_down
	jsr draw_cursor
	jmp main_loop
page_down
	lda top_item
	clc
	adc #ITEMS_PER_PAGE
	sta top_item
	jmp display_directory

up_pressed
	lda cur_item
	cmp #0
	beq main_loop
; single row up
	dec cur_item
; do we need to page up
	lda cur_item
	cmp top_item
	bmi page_up
	jsr draw_cursor
	jmp main_loop
page_up
	lda top_item
	sec
	sbc #ITEMS_PER_PAGE
	sta top_item
	jmp display_directory
	
return_pressed
	lda num_dir_entries
	bne return_pressed_ok	; check for empty dir
	jmp main_loop
return_pressed_ok
	lda cur_item
	sta $D500
	lda #CART_CMD_OPEN_ITEM
	jsr wait_for_cart

	lda $D501 ; look at return code from cart
	cmp #0
	beq directory_changed
	cmp #1
	beq file_loaded
	cmp #2
	beq xex_loaded
	cmp #3
	beq atr_loaded
	; if we get here, there was an error
	jsr display_error_msg_from_cart
	jmp read_current_directory
directory_changed
	jmp read_current_directory
file_loaded
	jmp reboot_to_selected_cart
xex_loaded
	jmp launch_xex
atr_loaded
	jmp launch_atr
		
back_pressed
	lda search_results_mode
	cmp #1
	beq exit_search_results
	lda #CART_CMD_UP_DIR
	jsr wait_for_cart
exit_search_results
	jmp read_current_directory
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

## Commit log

2017-03-02 add breakout pub
    [breakout.brd]
2017-03-02 Revert "add breakout pub"
    This reverts commit 04f853a2e4d8812c89c3d5930fbb2998b8b0dcbd.
    [breakout.brd]
2017-03-02 add breakout PCB
    [breakout.brd]

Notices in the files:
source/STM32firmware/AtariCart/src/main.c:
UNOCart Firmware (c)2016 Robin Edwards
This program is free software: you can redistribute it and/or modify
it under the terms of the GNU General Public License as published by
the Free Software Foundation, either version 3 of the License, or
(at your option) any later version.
